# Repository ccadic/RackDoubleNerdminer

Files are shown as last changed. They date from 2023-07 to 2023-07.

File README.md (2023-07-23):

# RackDouble Nerdminer V1.1 Prototype
Source files for the 2U Rack mount system holding up tp 15 nerdminers T Display S3.
This work is coming opensource GPL-3 
It allows you to host up to 15 small #nerdminer devices in a 19" rack cabinet.
You can link multiple cards, making bridges beteween the terminalbloc connectors

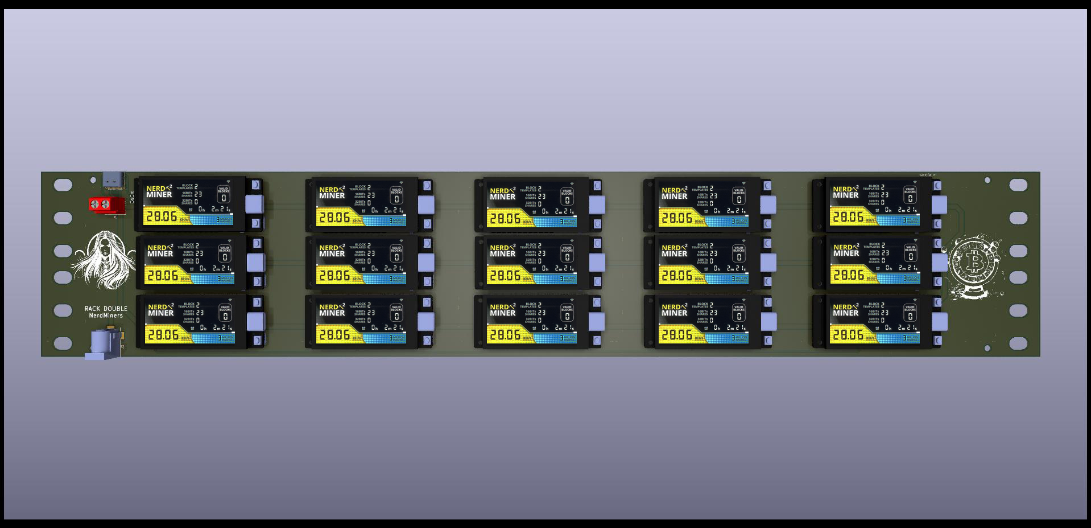
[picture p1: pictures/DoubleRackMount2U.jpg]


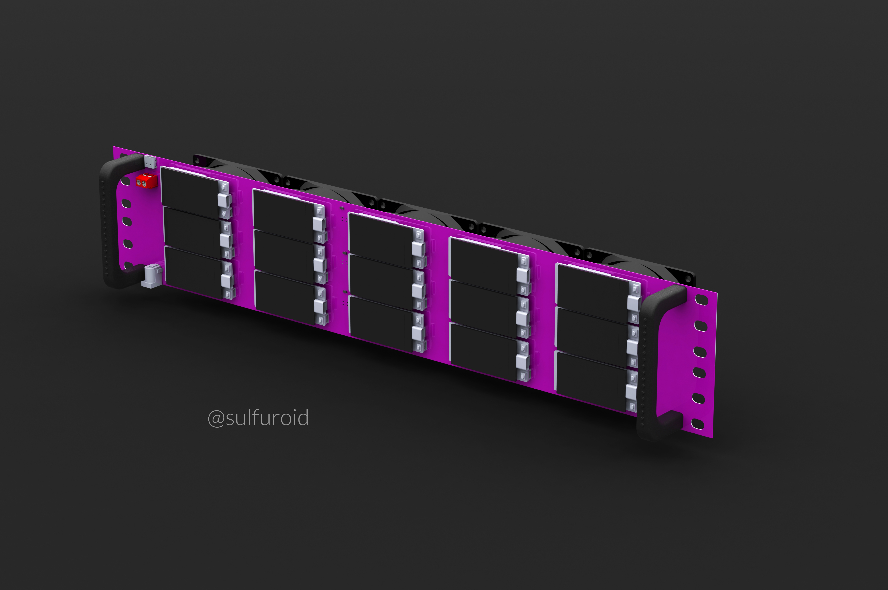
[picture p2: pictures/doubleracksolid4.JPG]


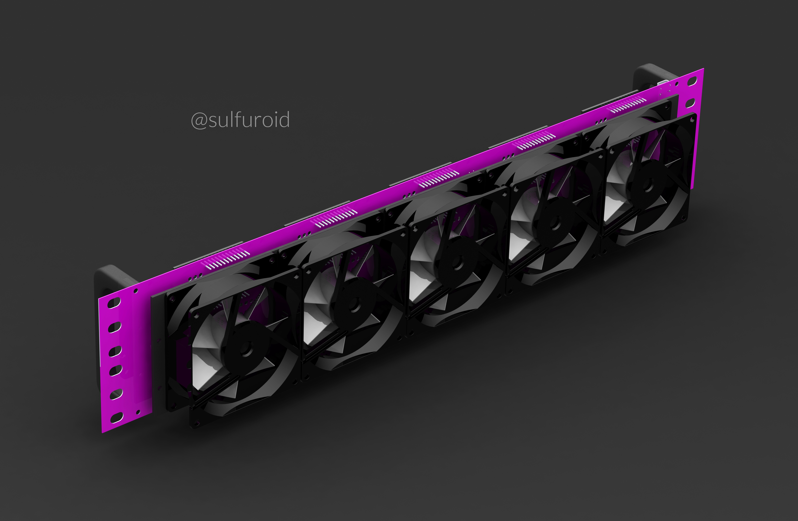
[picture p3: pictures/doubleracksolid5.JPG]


STEP 1: Make the PCBOARD
You get the GerberFiles in the rerp: /gerber

STEP 2: 3D printing
You get the 3D printable spacers and handles in /stl
You get the DXF file for lasercutting in /lasercut-dxf
Laser cut params for a K40 40 w CO2 laser: 20% , 10 mm speed 2 passes for black acrylic 2 mm thickness
You need to cut 2 files : on in front of the fans, one at the back.

STEP 3: Get the parts

5 x fans on Amazon - https://www.amazon.fr/gp/product/B093W7MT6S/ref=ppx_yo_dt_b_asin_title_o04_s00?ie=UTF8&psc=1

30 x 2.54 female header - 12 pins: https://fr.aliexpress.com/item/1005003610378386.html

1 Red terminal block : 20 Pcs/lot KF301-5.0-2P on https://fr.aliexpress.com/item/4000290521933.html

1 DC connnector: https://fr.aliexpress.com/item/1005003515013042.html model:  5.5x2.1mm

4x Hexa 3mm screws  (M3x6 mm down to M3x3mm) + M3 nuts

20 x M4x 20mm hexa + M3 nuts

Now have fun ...

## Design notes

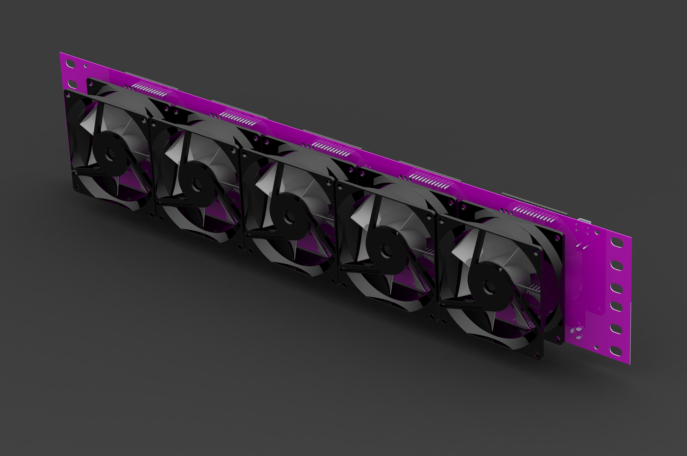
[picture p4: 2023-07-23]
pictures/doubleracksolid2.JPG

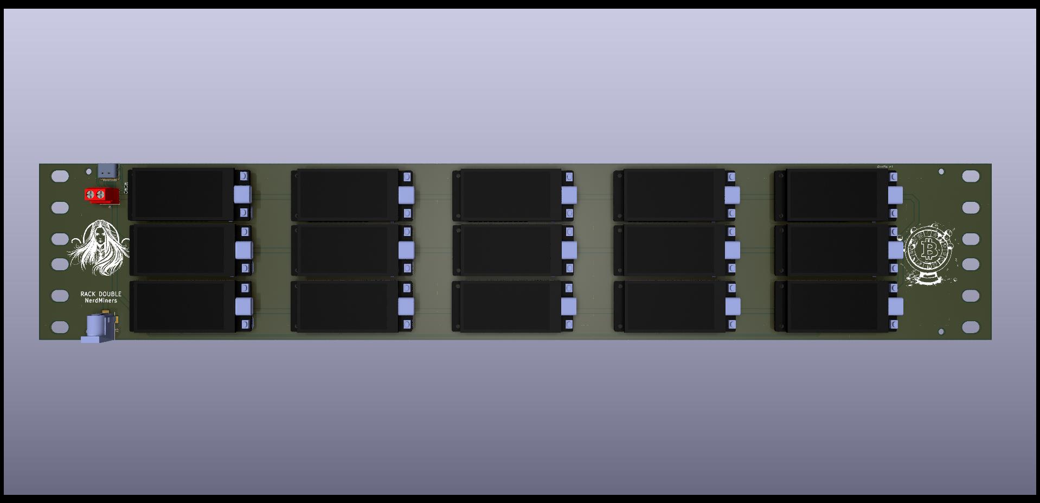
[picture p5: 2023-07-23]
pictures/DOUBLERACKT-DISPLAY-S3.jpg

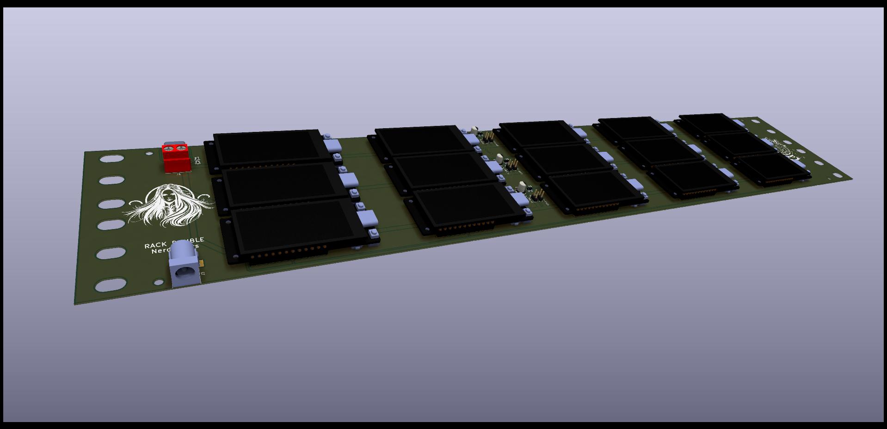
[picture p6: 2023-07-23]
pictures/DoubleRackMount2UB.jpg

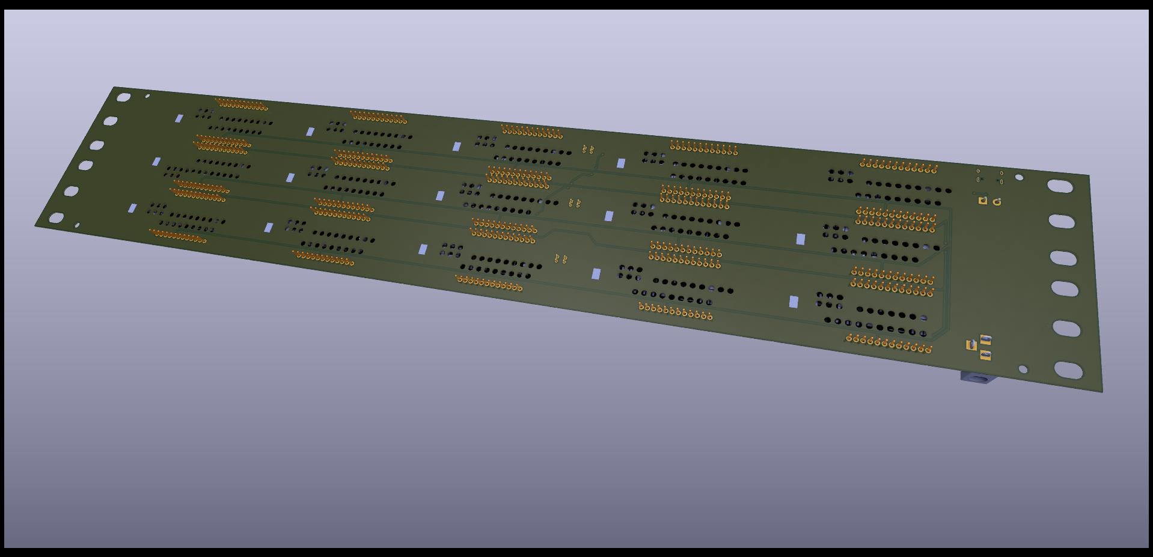
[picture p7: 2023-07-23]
pictures/DoubleRackMount2UD.jpg

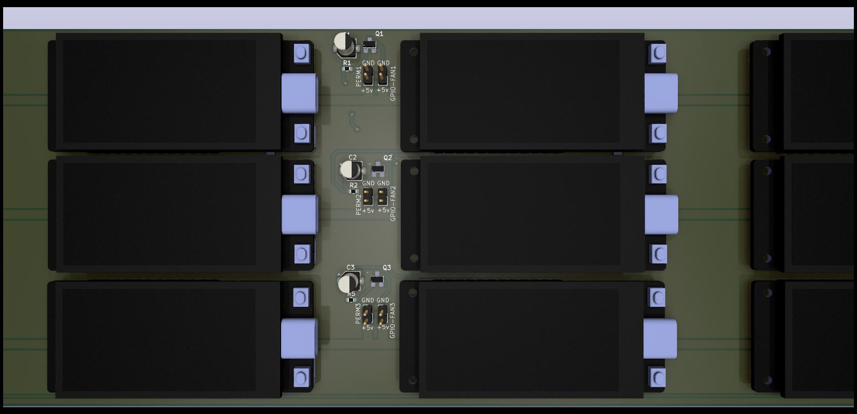
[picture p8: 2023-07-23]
pictures/DoubleRackMount2UC.jpg

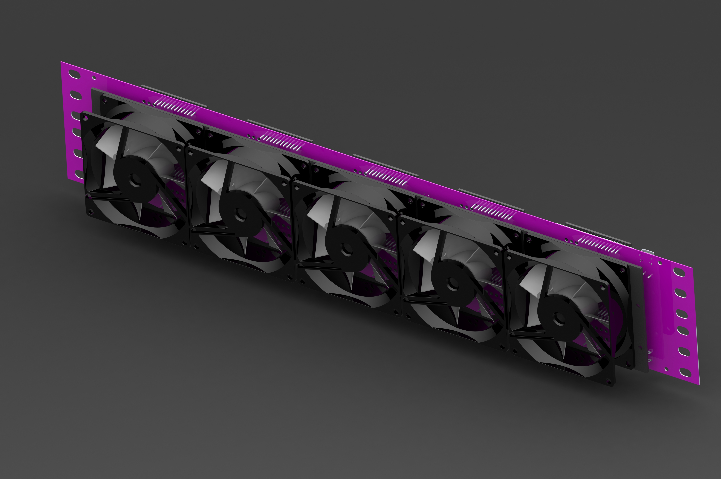
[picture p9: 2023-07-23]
pictures/doubleracksolid3.JPG

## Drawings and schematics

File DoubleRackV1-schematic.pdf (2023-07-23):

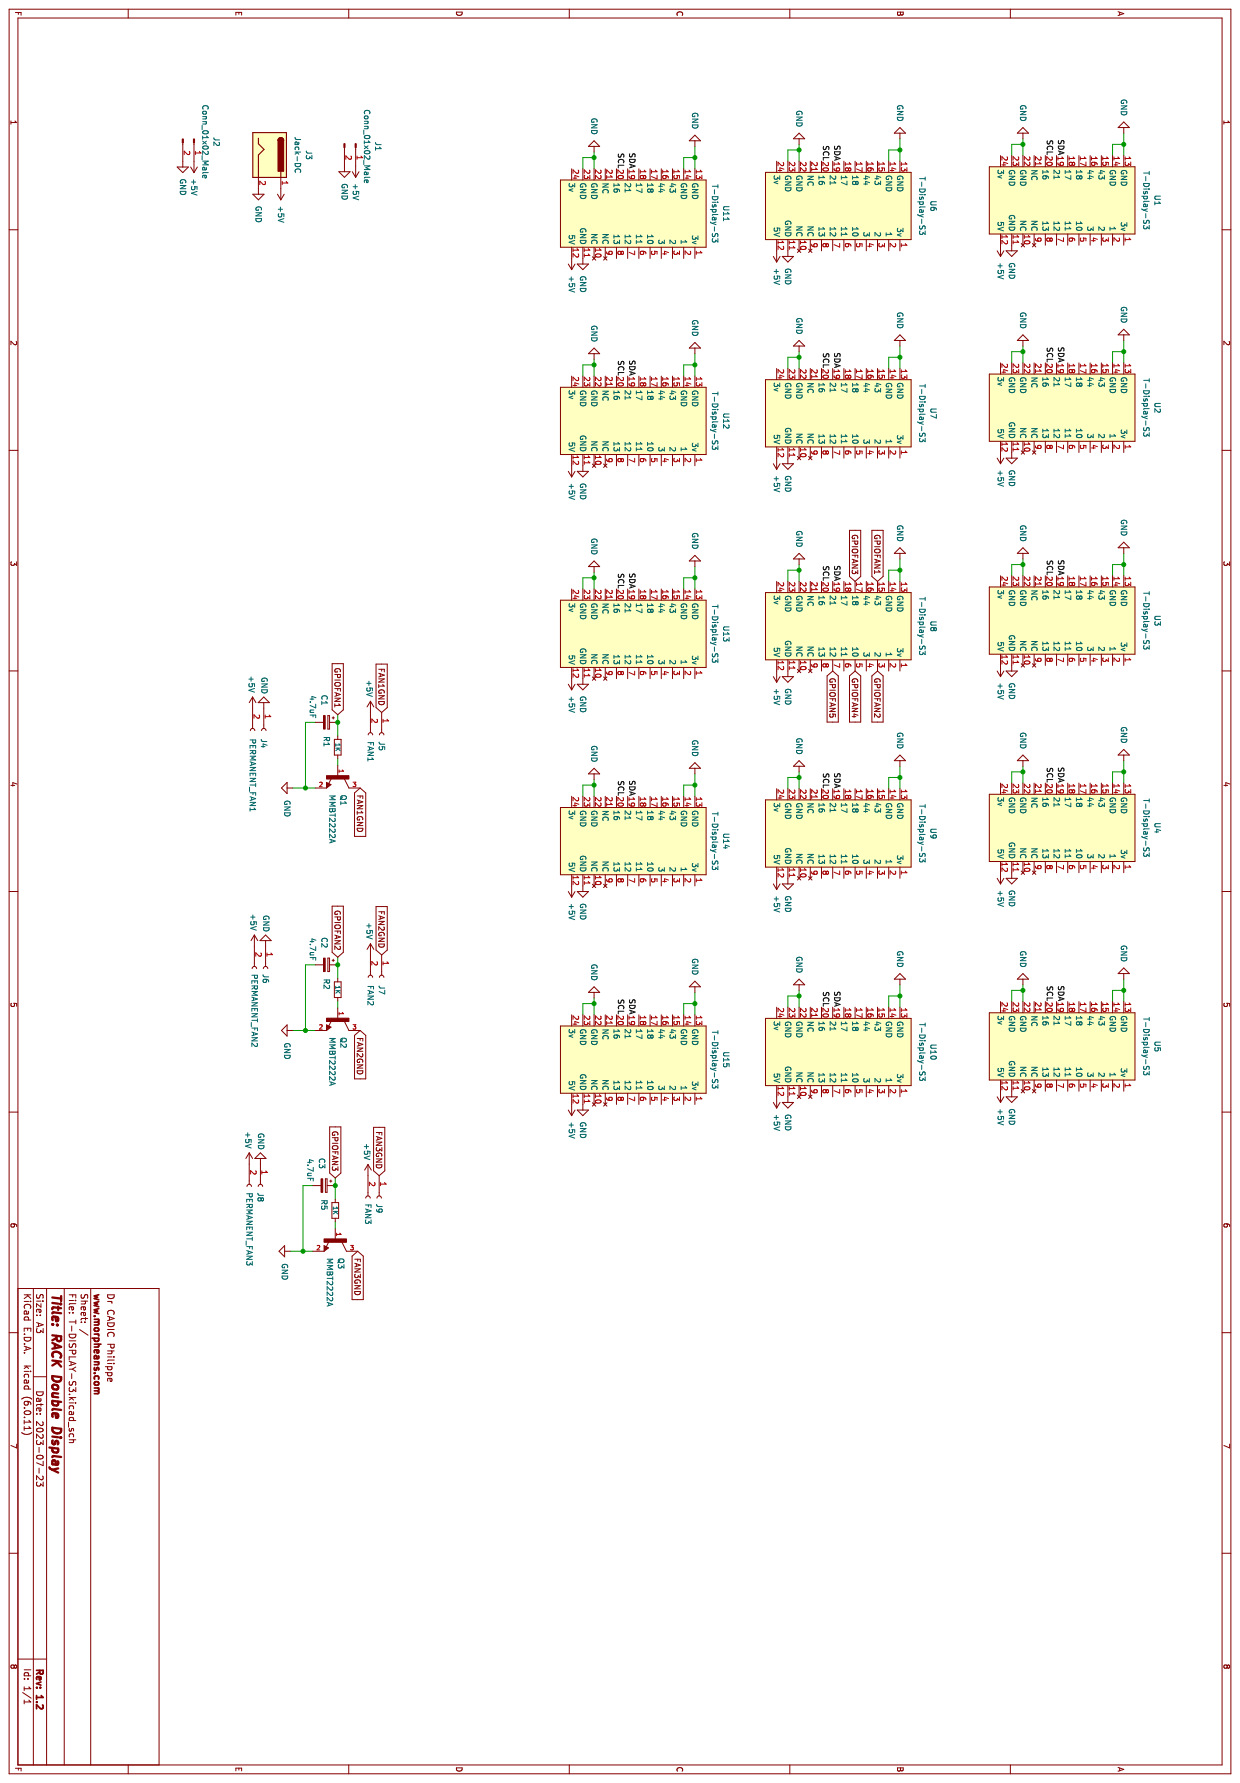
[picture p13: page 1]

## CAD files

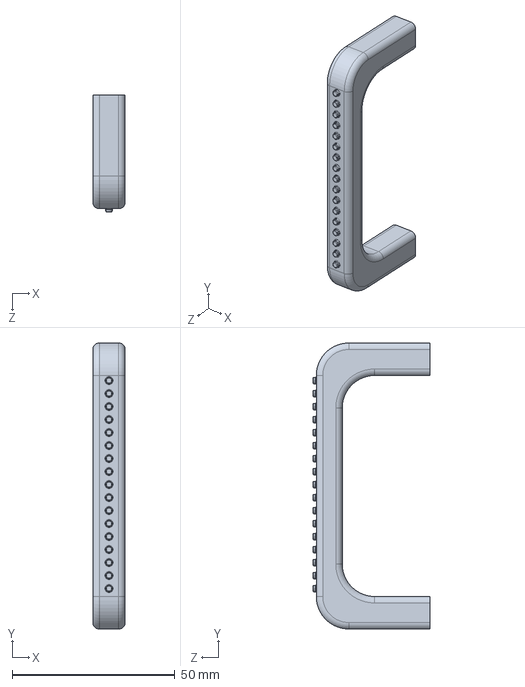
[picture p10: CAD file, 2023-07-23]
frontpanel-handle.STEP
10.0 x 88.0 x 36.0 mm

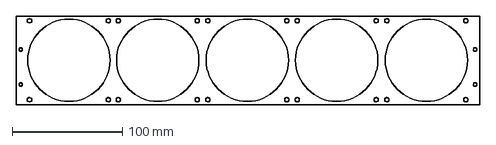
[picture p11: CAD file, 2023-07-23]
lasercut-dxf/laser-cut-5fans.DXF
420.0 x 80.0 mm

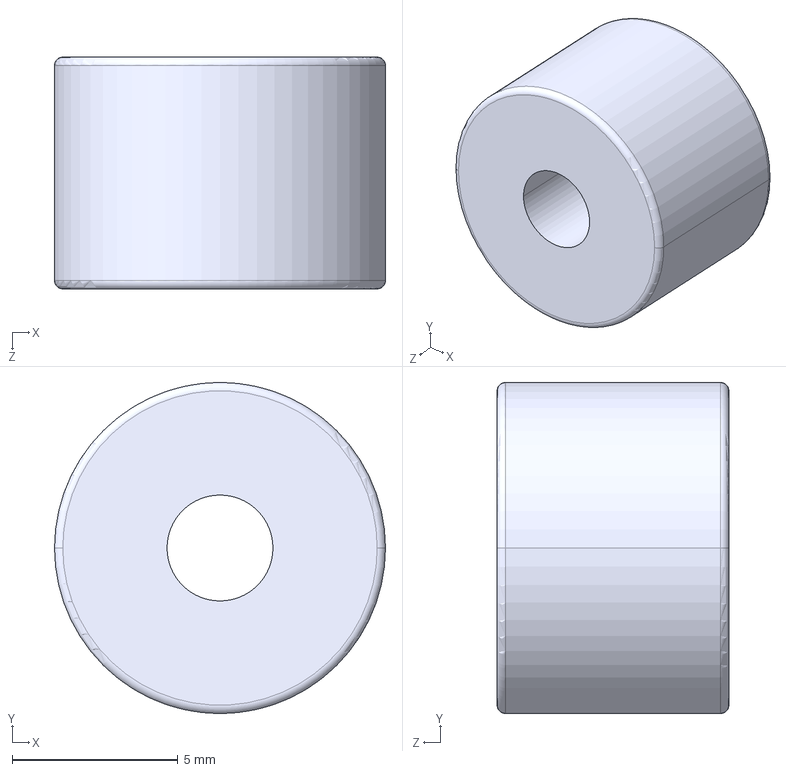
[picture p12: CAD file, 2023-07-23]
spacer5mm-fans.STEP
10.0 x 10.0 x 7.00 mm

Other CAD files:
frontpanel-handle.STL
spacer5mm-fans.SLDPRT
spacer5mm-fans.STL
